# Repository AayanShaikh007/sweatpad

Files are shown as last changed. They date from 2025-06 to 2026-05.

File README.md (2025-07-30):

# Sweatpad- the hackpad for sweats
**Scroll down to see the finished product!**

I always found most gaming keyboards to be difficult to use and somewhat non ergonomic. This prompted me to create the sweatpad, a shortened keyboard with only the keys that you may need to play most fps games. It also features RGB lighting, a OLED display to show data/modes.

## Complete Assembly (without keys):
Some images of what the finished product should approximately look like. 




## PCB and Schematic

 



## Case and Exploded View



## BOM 
- 1 SEEEDUINO XIAO RP2040
- 16x MX-Style switches (preferrably MX-Brown)
- 16x 1N4148 diodes
- 1x SSD1306 LED (I2C)
- 16 Blank DSA keycaps (White)
- 16x SK6812 MINI-E LEDs
- 4x M3x16mm screws, and corresponding nuts

## Notes
Although this project should have been really simple, i overcomplicated it by adding a bunch of switches because of my original idea for the project, but at least now it would be easier for me to design my full/60% keyboard. The PCB was larger than the 100x100 mm restriction, so i had to shorten it, leading to some unsightly changes in the case- but they shouldn't have any effect on the functionality. 

# Finished Product



# Youtube Demo Link

https://youtu.be/8_cZmQdGrSU

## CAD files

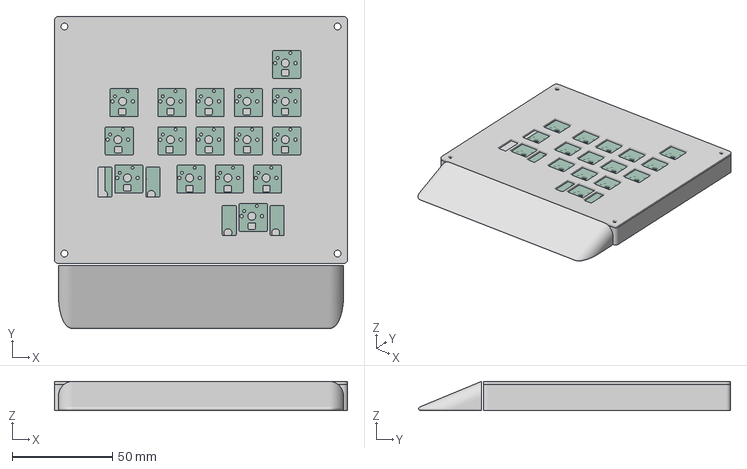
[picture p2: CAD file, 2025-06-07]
CAD/completeassembly.3mf
146.0 x 155.3 x 14.5 mm

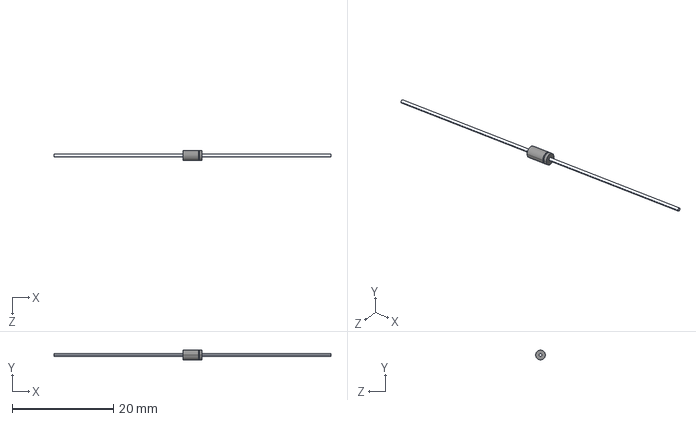
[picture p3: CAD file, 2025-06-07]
PCB/assets/footprints/diode1n4148/1N4148.step
54.6 x 1.91 x 1.91 mm

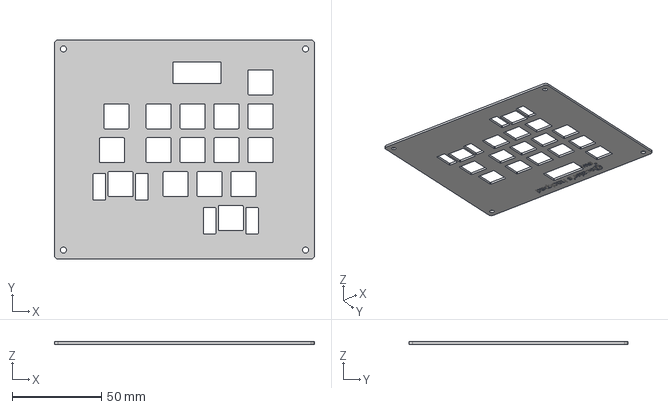
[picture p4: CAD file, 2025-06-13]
Production/top v2.step
146.0 x 123.0 x 1.50 mm

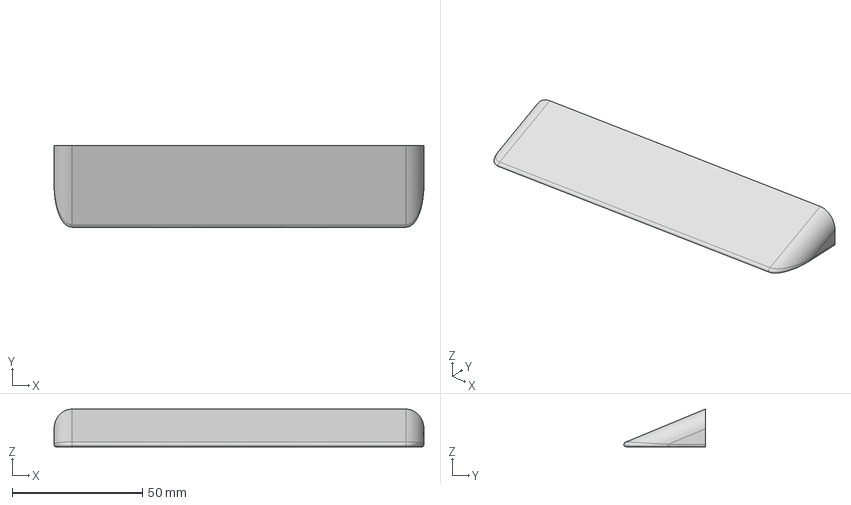
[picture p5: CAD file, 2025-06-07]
Production/armrest.step
142.0 x 31.3 x 14.5 mm

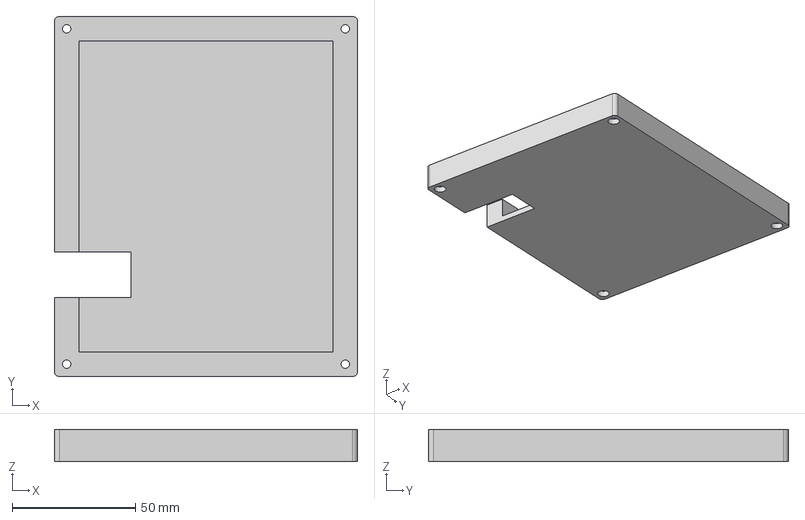
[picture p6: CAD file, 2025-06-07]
Production/bottom.step
123.0 x 146.0 x 13.0 mm

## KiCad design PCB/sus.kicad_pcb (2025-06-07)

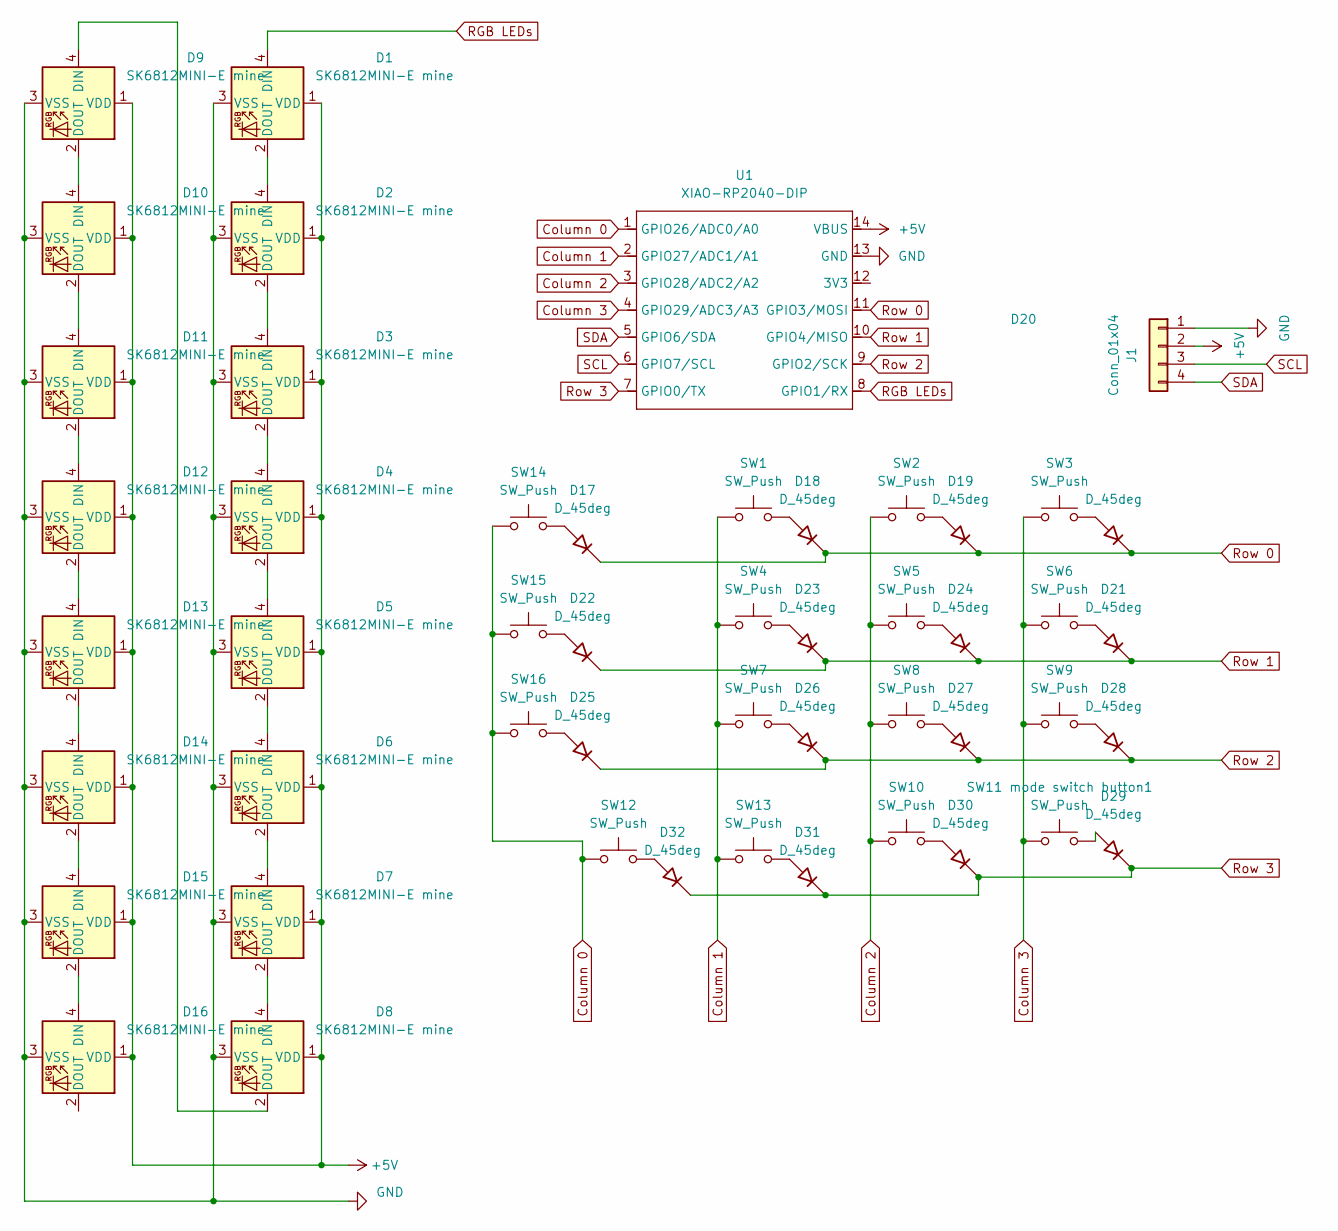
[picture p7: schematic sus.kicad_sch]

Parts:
D1, D2, D3, D4, D5, D6, D7, D8, D9, D10, D11, D12, D13, D14, D15, D16: SK6812MINI-E mine; BAcklight
D17, D18, D19, D20, D21, D22, D23, D24, D25, D26, D27, D28, D29, D30, D31, D32: D_45deg; DO35-7
J1: Conn_01x04; SSD1306-0.91-OLED-4pin-128x32
SW1, SW2: SW_Push; SW_Cherry_MX_2.25u_PCB
SW3: SW_Push; SW_Cherry_MX_1.75u_PCB
SW4: SW_Push; SW_Cherry_MX_1.50u_PCB
SW5, SW6, SW7, SW8, SW9, SW10, SW11 mode switch button1, SW12, SW13, SW14, SW15, SW16: SW_Push; SW_Cherry_MX_1.00u_PCB
U1: XIAO-RP2040-DIP

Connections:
+5V: D1.1 (VDD), D2.1 (VDD), D3.1 (VDD), D4.1 (VDD), D5.1 (VDD), D6.1 (VDD), D7.1 (VDD), D8.1 (VDD), D9.1 (VDD), D10.1 (VDD), D11.1 (VDD), D12.1 (VDD), D13.1 (VDD), D14.1 (VDD), D15.1 (VDD), D16.1 (VDD), J1.2, U1.14 (VBUS)
Column 0: SW12.1, SW14.1, SW15.1, SW16.1, U1.1 (GPIO26/ADC0/A0)
Column 1: SW1.1, SW4.1, SW7.1, SW13.1, U1.2 (GPIO27/ADC1/A1)
Column 2: SW2.1, SW5.1, SW8.1, SW10.1, U1.3 (GPIO28/ADC2/A2)
Column 3: SW3.1, SW6.1, SW9.1, SW11 mode switch button1.1, U1.4 (GPIO29/ADC3/A3)
GND: D1.3 (VSS), D2.3 (VSS), D3.3 (VSS), D4.3 (VSS), D5.3 (VSS), D6.3 (VSS), D7.3 (VSS), D8.3 (VSS), D9.3 (VSS), D10.3 (VSS), D11.3 (VSS), D12.3 (VSS), D13.3 (VSS), D14.3 (VSS), D15.3 (VSS), D16.3 (VSS), J1.1, U1.13 (GND)
unnamed: D1.2 (DOUT), D2.4 (DIN)
unnamed: D2.2 (DOUT), D3.4 (DIN)
unnamed: D3.2 (DOUT), D4.4 (DIN)
unnamed: D4.2 (DOUT), D5.4 (DIN)
unnamed: D5.2 (DOUT), D6.4 (DIN)
unnamed: D6.2 (DOUT), D7.4 (DIN)
unnamed: D7.2 (DOUT), D8.4 (DIN)
unnamed: D8.2 (DOUT), D9.4 (DIN)
unnamed: D9.2 (DOUT), D10.4 (DIN)
unnamed: D10.2 (DOUT), D11.4 (DIN)
unnamed: D11.2 (DOUT), D12.4 (DIN)
unnamed: D12.2 (DOUT), D13.4 (DIN)
unnamed: D13.2 (DOUT), D14.4 (DIN)
unnamed: D14.2 (DOUT), D15.4 (DIN)
unnamed: D15.2 (DOUT), D16.4 (DIN)
unnamed: D17.2 (A), SW14.2
unnamed: D18.2 (A), SW1.2
unnamed: D19.2 (A), SW2.2
unnamed: D20.2 (A), SW3.2
unnamed: D21.2 (A), SW6.2
unnamed: D22.2 (A), SW15.2
unnamed: D23.2 (A), SW4.2
unnamed: D24.2 (A), SW5.2
unnamed: D25.2 (A), SW16.2
unnamed: D26.2 (A), SW7.2
unnamed: D27.2 (A), SW8.2
unnamed: D28.2 (A), SW9.2
unnamed: D29.2 (A), SW11 mode switch button1.2
unnamed: D30.2 (A), SW10.2
unnamed: D31.2 (A), SW13.2
unnamed: D32.2 (A), SW12.2
RGB LEDs: D1.4 (DIN), U1.8 (GPIO1/RX)
Row 0: D17.1 (K), D18.1 (K), D19.1 (K), D20.1 (K), U1.11 (GPIO3/MOSI)
Row 1: D21.1 (K), D22.1 (K), D23.1 (K), D24.1 (K), U1.10 (GPIO4/MISO)
Row 2: D25.1 (K), D26.1 (K), D27.1 (K), D28.1 (K), U1.9 (GPIO2/SCK)
Row 3: D29.1 (K), D30.1 (K), D31.1 (K), D32.1 (K), U1.7 (GPIO0/TX)
SCL: J1.3, U1.6 (GPIO7/SCL)
SDA: J1.4, U1.5 (GPIO6/SDA)

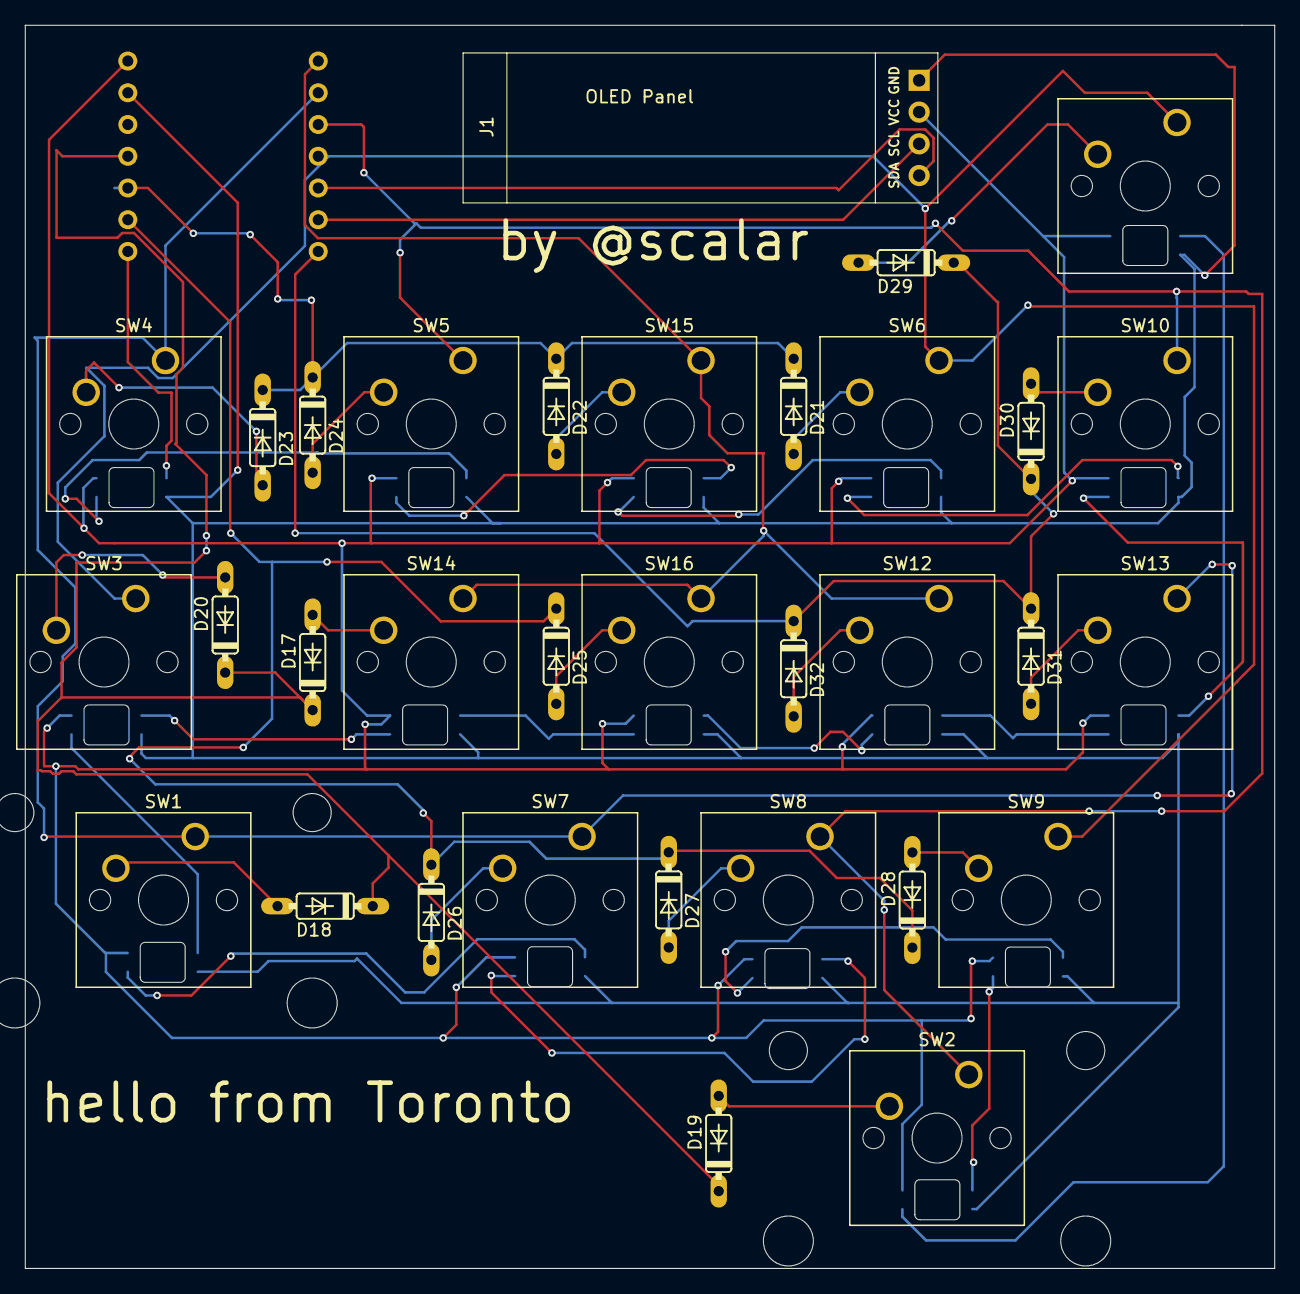
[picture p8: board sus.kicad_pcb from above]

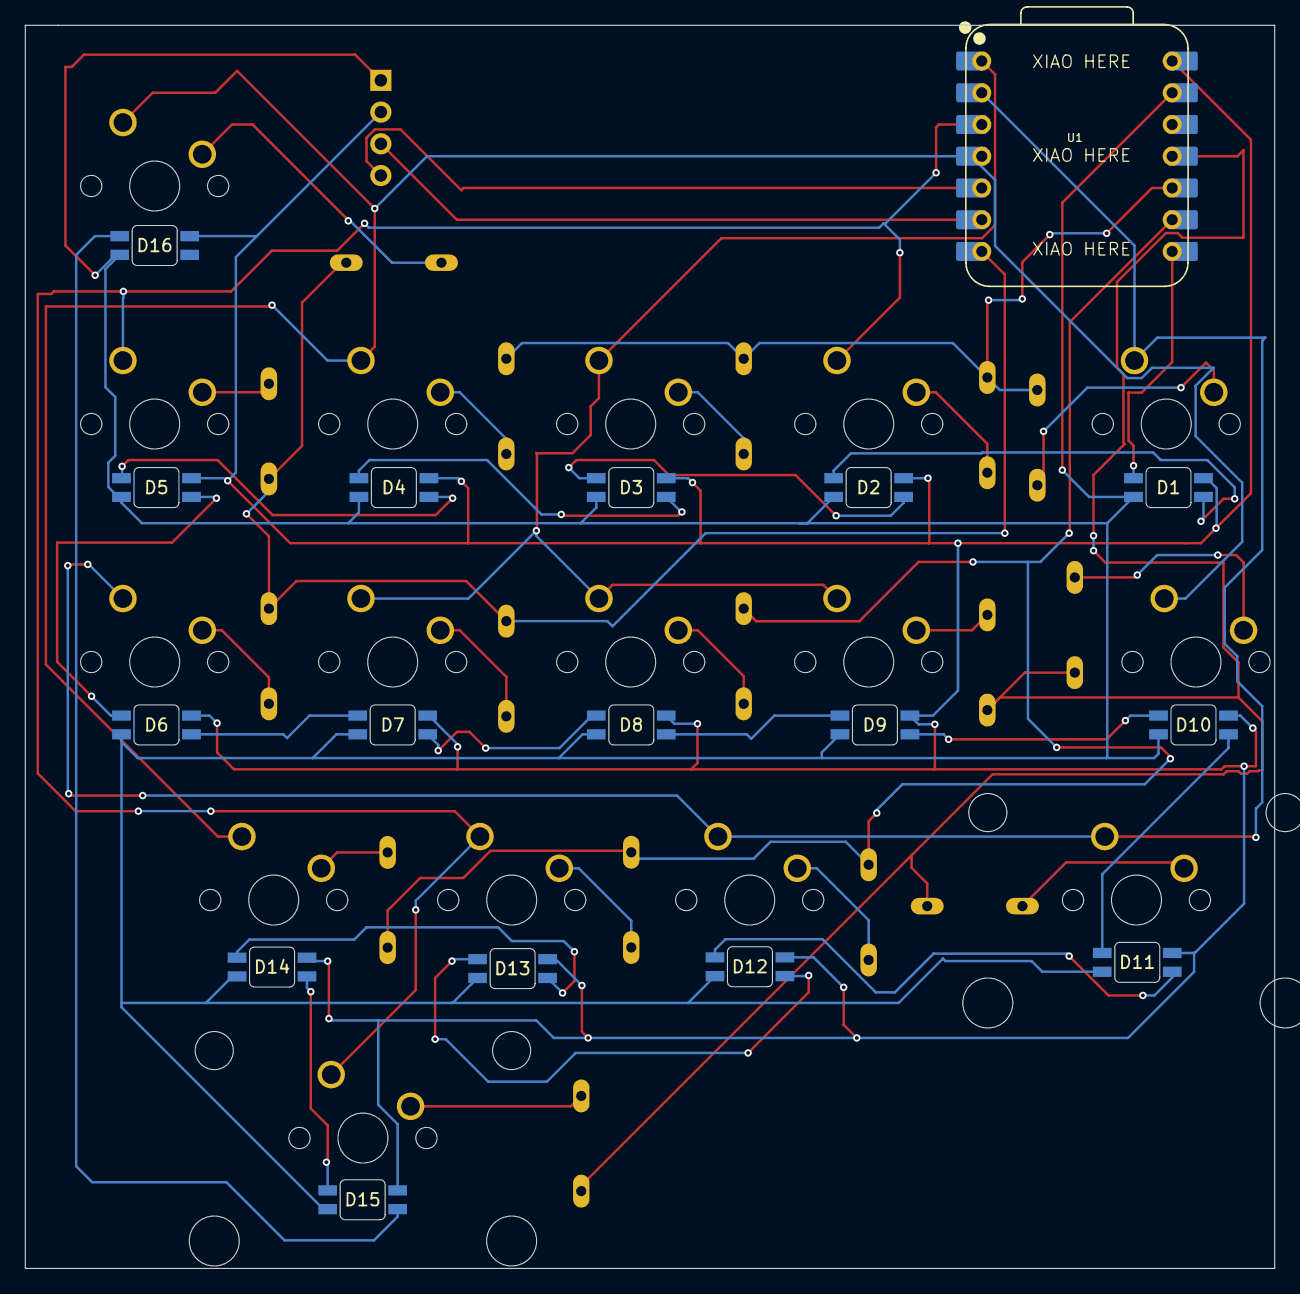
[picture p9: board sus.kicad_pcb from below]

Board: 2 copper layers, 100.0 x 99.5 mm, 50 parts (17 on the bottom side), 44 nets.

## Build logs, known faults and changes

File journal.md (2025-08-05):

---
title: "sweatpad"
author: "@Scalar"
description: "A gaming centric keypad aimed at removing the issues in modern keyboards"
created_at: "2025-06-04"
---

# June 4th
- Today I continued working on the hackpad. I had already finished designing most of the schmatic and just need to make some small changes now.
- I was having some difficulty getting the required footprints, but I was ultimately able to find them using **snapeda.com** (should use this in the future), where i could find the specific part and their footprints.
- With the schematic fully completed, I proceeded to work on the PCB.
- I initally had some issues importing the schematic to the PCB because some footprints apparently do not label the pins numerically, but rather as A and C (anode/cathode). I fixed this in the footprint editor.
- I thus began arranging parts on the PCB- which took me some time to ensure that everything was arranged properly in the way I want it in the final design.

# July 5th
Today I started the build process by soldering the diodes in. Since the hackpad kit hadnt arrived yet, I was limited to parts from my full sized keyboard build (scalars-keyboard on github). 

# July 9th and 10th
Today the hackpad parts arrived. I made it my goal to finish the project before I left for undercity on the 11th. I soldered the remaining parts such as the keyswitches in and started uploading the firmware to the board. After troubleshooting with the hardware for a little bit, I found that some of the keyswitch designations in KMK were off causing the keys to be all over the place. After fixing this issue, the hackpad pcb was completed and all that was left was the case. 


# July 20th
Before I left for undercity I started printing the bottom case for the hackpad. Now back from undercity, I tried to print my top plate but I encountered a problem- I had mistakenly soldered the switches in first causing the top plate to not fit. I had to spend a few hours editing the top plate to enlarge the square holes for the keyswitches so that it would fit over the keyswitches. With that done, I assembled the case, completing the project.



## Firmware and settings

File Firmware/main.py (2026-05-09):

import board
from kmk.kmk_keyboard import KMKKeyboard
from kmk.keys import KC
from kmk.scanners import DiodeOrientation
from kmk.modules.macros import Macros

keyboard = KMKKeyboard()
keyboard.modules = [Macros()]

keyboard.col_pins = (board.A0, board.A1, board.A2, board.A3)  # D0–D3
keyboard.row_pins = (board.D10, board.D9, board.D8, board.D6)  # D10, D9, D8, D6

keyboard.diode_orientation = DiodeOrientation.COL2ROW

keyboard.keymap = [
    [KC.A, KC.LSHIFT, KC.SPACE, KC.CAPS, KC.W, KC.TAB, KC.Q, KC.E, KC.S, KC.Z, KC.X, KC.C, KC.D, KC.F, KC.R, KC.G],

]

keyboard.go()

    # [KC.A, KC.LSHIFT, KC.SPACE, KC.CAPS, KC.W, KC.TAB, KC.Q, KC.E, KC.S, KC.Z, KC.X, KC.C, KC.D, KC.F, KC.R, KC.G],

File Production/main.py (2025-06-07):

import board
import busio

from kmk.kmk_keyboard import KMKKeyboard
from kmk.keys import KC
from kmk.scanners import DiodeOrientation
from kmk.modules.macros import Macros

from kmk.extensions.display import Display, TextEntry
from kmk.extensions.LED import LED, AnimationModes
from kmk.extensions.display.ssd1306 import SSD1306


col_0 = board.GP1
col_1 = board.GP2
col_2 = board.GP3
col_3 = board.GP4


row_0 = board.GP11
row_1 = board.GP10
row_2 = board.GP9
row_3 = board.GP7

led_pin = board.GP8

oled_bus = busio.I2C(board.GP_SCL, board.GP_SDA)

oled_driver = SSD1306(i2c=oled_bus, device_address=0x3C);

display = Display(
    display=oled_driver,
    width=128,
    height=64,   # isnt this supposed to be 32 bit
    dim_time=10,
    dim_target=0.2,
    off_time=1200,
    brightness=0.8
);

keyboard = KMKKeyboard()
keyboard.diode_orientation = DiodeOrientation.COL2ROW # the stripe (+) points towards the row 

keyboard.col_pins = (col_0, col_1, col_2, col_3);
keyboard.row_pins = (row_0, row_1, row_2, row_3);

keyboard.keymap = [
    [KC.Q,      KC.W,     KC.E,      KC.R  ],  # Row 0
    [KC.A,      KC.S,     KC.D,      KC.F  ],  
    [KC.LSHIFT, KC.LTAB,  KC.LCAPS,  KC.SPACE  ],  #THIS NEEDS FIXING -- the actual keys are arranged differently
    [KC.Z,      KC.X,     KC.C,      KC.V],  
]

if __name__ == '__main__':
    keyboard.go()

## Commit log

2025-06-13 adding oled hole changes
2026-05-09 Refactor main.py by removing unused code and updating pins
    Removed unused imports and updated pin assignments for the keyboard.
